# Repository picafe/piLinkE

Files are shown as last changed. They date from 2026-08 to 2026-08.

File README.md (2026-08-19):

# piLinkE

A compact USB-C clone of WCH's [WCH-LinkE](https://www.wch.cn/products/WCH-Link.html) debugger, designed in Altium. It programs and debugs WCH RISC-V MCUs over SWD, can be switched into DAPLink / ARM SWD mode, and has a USB-UART.

This is my own version, on a 4-layer PCB meant to be cheap to manufacture at JLCPCB, with more specific features.

Production files (Gerbers, drill, BOM) are in [`outputs/`](outputs/). Design files are in [`pcb/`](pcb/).

## Why this exists

I wanted an excuse to use Altium so I made this, which I consider to be a relatively simple board. The schematic follows the same overall design as existing OSHWHub clones ([fanhuacloud](https://web.archive.org/web/20240525210835/https://oshwhub.com/fanhuacloud/wch-linke/), with a CH32V305FBP6 as the LinkE MCU. As a bonus, the same chip can run [high-speed ARM DAPLink firmware](https://github.com/prosper00/CH32V305-DAPLink-HS).

## Pictures

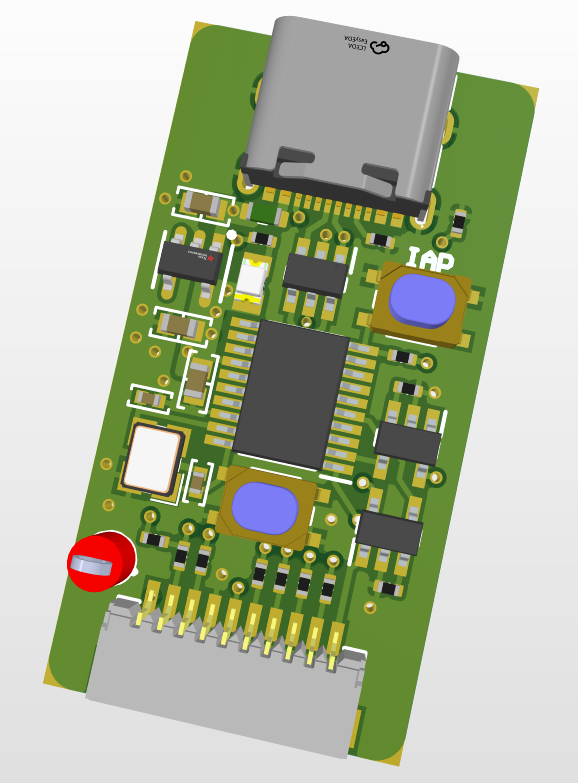
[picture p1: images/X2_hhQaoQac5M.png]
3D model


*3D model.*

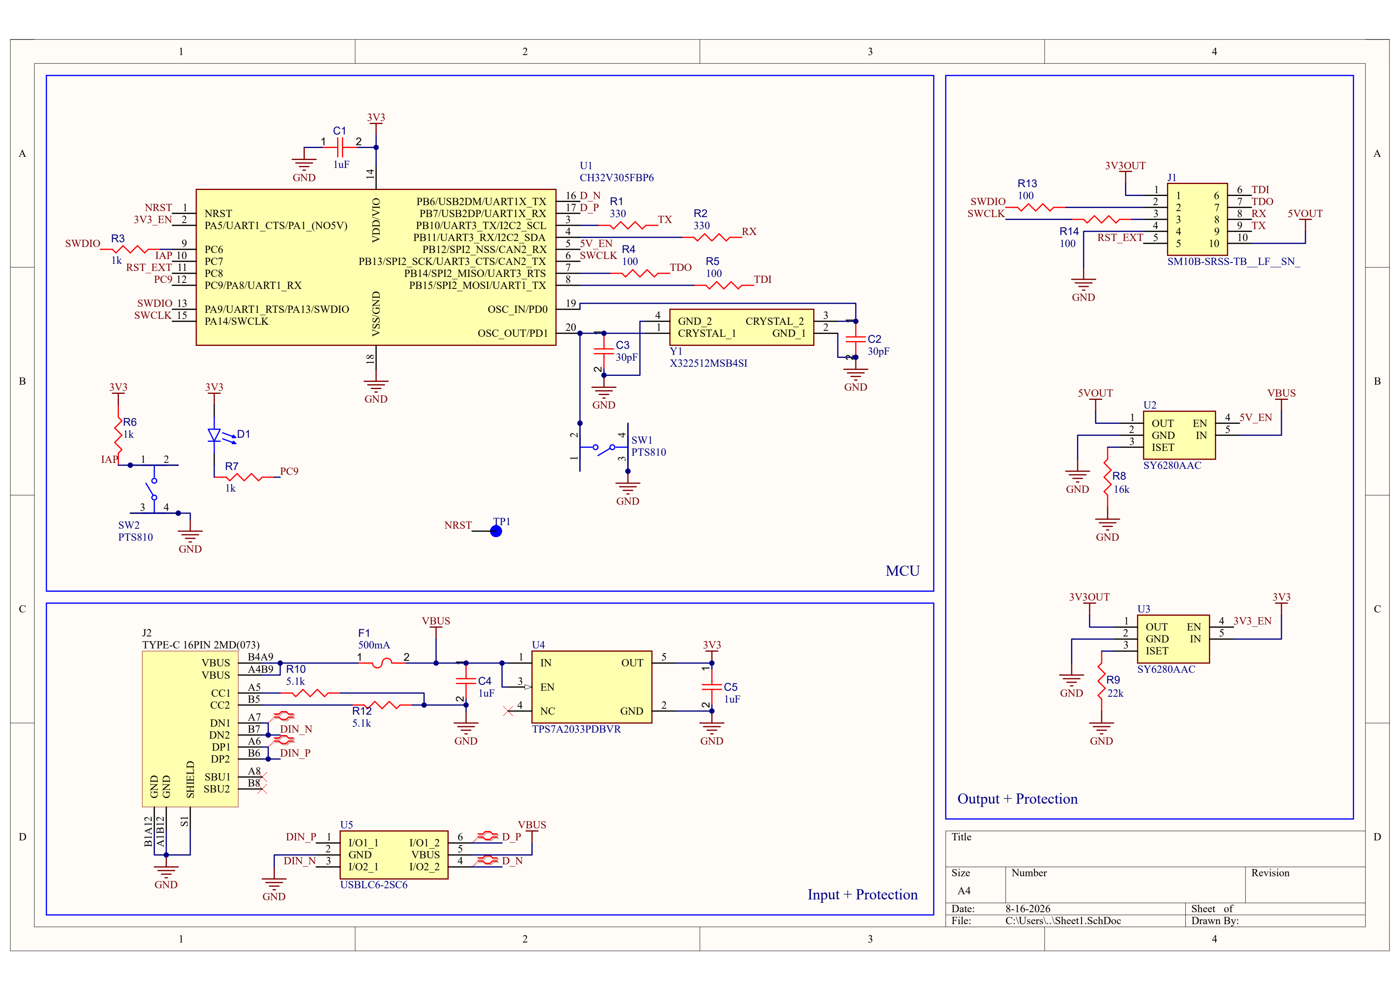
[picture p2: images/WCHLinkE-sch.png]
Schematic


*Schematic.*

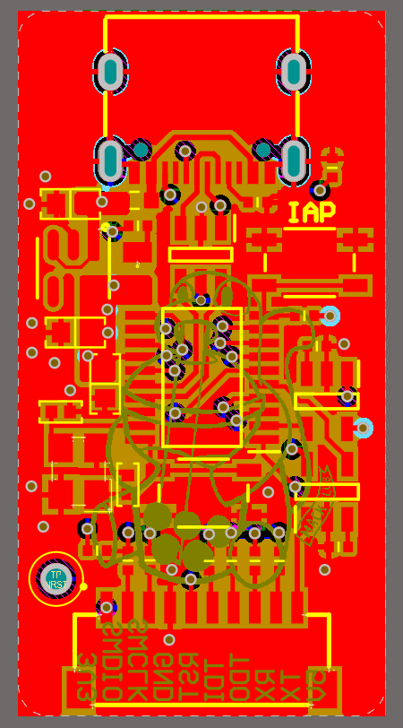
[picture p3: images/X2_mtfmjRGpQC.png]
PCB front


*PCB layout front*

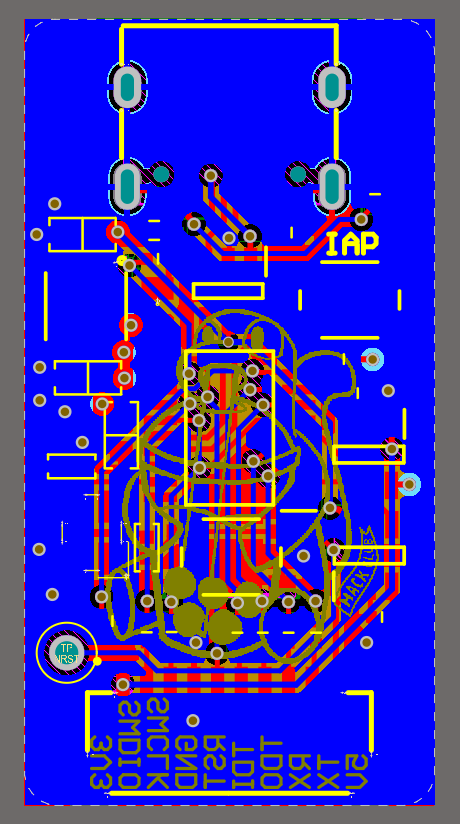
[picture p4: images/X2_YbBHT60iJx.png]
PCB back


*PCB layout back*

## Connections

The only cable is the target debug lead: a 10-pin JST-SH to Dupont harness.

The header pinout was copied so a stock **WeAct Studio Mini Debugger (ST-Link)** or **WeAct Logic Analyzer** JST-SH-to-Dupont cable is mostly colour-compatible.

Pin functions are also silkscreened on the board, next to the connector:

| Pin | Function |
| ---: | --- |
| 1 | 3V3 |
| 2 | SWDIO / TMS |
| 3 | SWCLK / TCK |
| 4 | GND |
| 5 | RST |
| 6 | TDI |
| 7 | TDO |
| 8 | RX |
| 9 | TX |
| 10 | 5V |

Buttons:

- **IAP** - hold while plugging in USB to enter IAP / bootloader mode
- **Mode** - hold while plugging in USB to switch RV (WCH) vs DAPLink mode

## How to flash

The CH32V305 needs WCH-LinkE firmware (or DAPLink, if you want ARM). Two options:

### Another WCH-LinkE

Use a working LinkE (or any WCH programmer) to flash `FIRMWARE_CH32V305.bin` onto this board over SWD, the same way you would program any other CH32V305.

### IAP, no second debugger

[wlink-iap](https://github.com/cjacker/wlink-iap) can upgrade / downgrade LinkE firmware over USB without holding the IAP button or buying a second dongle. Follow the instructions in that repo. Short version:

```
git clone https://github.com/cjacker/wlink-iap
cd wlink-iap
make
sudo make install

wlink-iap -f FIRMWARE_CH32V305.bin
```

For a full chip erase / APP+IAP image, enter IAP first (`wlink-iap -i`, or hold **IAP** while plugging in USB) and then follow the [wlink-iap](https://github.com/cjacker/wlink-iap) notes.

To leave IAP if you entered it by accident: `wlink-iap -q`.

After the stock LinkE firmware is on the board, use [WCH-LinkUtility](https://www.wch.cn/downloads/WCH-LinkUtility_ZIP.html) or MounRiver Studio to switch RV vs DAP mode.

## Known issues

- A few silkscreen-to-exposed-copper DRC errors were left as-is; they are cosmetic.
- Vias are tented. Altium's solder-mask sliver rule complains about vias close to exposed copper.

## Bill of materials

Prices are rough LCSC estimates (Aug 2026) and will move. They do not include the JST-SH cable.

| Designator | Value | Footprint | Qty | LCSC | Unit cost (est.) | Line total (est.) |
| --- | --- | --- | ---: | --- | ---: | ---: |
| C1, C4, C5 | 1 µF | 0603 | 3 | [C126631](https://www.lcsc.com/product-detail/C126631.html) | $0.08 | $0.23 |
| C2, C3 | 30 pF | 0402 | 2 | [C526980](https://www.lcsc.com/product-detail/C526980.html) | $0.005 | $0.01 |
| D1 | Green LED | 0805 | 1 | [C84256](https://www.lcsc.com/product-detail/C84256.html) | $0.01 | $0.01 |
| F1 | 500 mA PTC | 0603 | 1 | [C7472536](https://www.lcsc.com/product-detail/C7472536.html) | $0.04 | $0.04 |
| J1 | 10-pin JST-SH | SMD 1 mm | 1 | [C5340780](https://www.lcsc.com/product-detail/C5340780.html) | $0.07 | $0.07 |
| J2 | USB-C 16P | SMD | 1 | [C165948](https://www.lcsc.com/product-detail/C165948.html) | $0.19 | $0.19 |
| R1, R2 | 330 Ω | 0402 | 2 | [C25104](https://www.lcsc.com/product-detail/C25104.html) | $0.007 | $0.014 |
| R3, R6, R7 | 1 kΩ | 0402 | 3 | [C11702](https://www.lcsc.com/product-detail/C11702.html) | $0.007 | $0.021 |
| R4, R5, R13, R14 | 100 Ω | 0402 | 4 | [C25076](https://www.lcsc.com/product-detail/C25076.html) | $0.008 | $0.032 |
| R8 | 16 kΩ | 0402 | 1 | [C25759](https://www.lcsc.com/product-detail/C25759.html) | $0.016 | $0.016 |
| R9 | 22 kΩ | 0402 | 1 | [C25768](https://www.lcsc.com/product-detail/C25768.html) | $0.006 | $0.006 |
| R10, R12 | 5.1 kΩ | 0402 | 2 | [C25905](https://www.lcsc.com/product-detail/C25905.html) | $0.004 | $0.008 |
| SW1, SW2 | Tactile switch | SMD | 2 | [C5363473](https://www.lcsc.com/product-detail/C5363473.html) | $0.03 | $0.06 |
| TP1 | Test point | Through hole | 1 | [5000](https://www.digikey.com/en/products/detail/keystone-electronics/5000/301) | $0.25 | $0.25 |
| U1 | CH32V305FBP6 | TSSOP-20 | 1 | [C5123443](https://www.lcsc.com/product-detail/C5123443.html) | $1.90 | $1.90 |
| U2, U3 | SY6280AAC | SOT-23-5 | 2 | [C55136](https://www.lcsc.com/product-detail/C55136.html) | $0.10 | $0.19 |
| U4 | TPS7A2033PDBVR | SOT-23-5 | 1 | [C2862740](https://www.lcsc.com/product-detail/C2862740.html) | $0.24 | $0.24 |
| U5 | USBLC6-2SC6 | SOT-23-6 | 1 | [C2827654](https://www.lcsc.com/product-detail/C2827654.html) | $0.04 | $0.04 |
| Y1 | 12 MHz | 3225 | 1 | [C9002](https://www.lcsc.com/product-detail/C9002.html) | $0.10 | $0.10 |
| | | | | **Total (components only)** | | **~$3.43** |

The PCB + stencil cost is around $10 on JLCPCB.

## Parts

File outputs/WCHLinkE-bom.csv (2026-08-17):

Name | Description | Designator | Footprint | LibRef | Quantity | LCSC
Capacitors,C126631,1uF | Capacitor | C1, C4, C5 | CAP 0603_1608 | Capacitors | 3 | C126631
Capacitors,C526980,30pF | Capacitor | C2, C3 | CAP 0402_1005 | Capacitors | 2 | C526980
KT-0805G | -40?~+85? 100mW 120° 2.6V~3.1V 430mcd 513nm~528nm 525nm 5mA Emerald Green 0805 LED Indication - Discrete ROHS | D1 | KT-0805G | CMP-007-00006-5 | 1 | C84256
Fuses,500mA,C7472536 | Fuse | F1 | LFUS-467_V | Fuses | 1 | C7472536
SM10B-SRSS-TB__LF__SN_ | Connector | J1 | SM10B-SRSS-TB | SM10B-SRSS-TB__LF__SN_ | 1 | C5340780
TYPE-C 16PIN 2MD(073) | USB-C (USB TYPE-C) Receptacle Connector 16 Position Surface Mount, Right Angle | J2 | USB-C-SMD_TYPE-C-16PIN-2MD-073 | TYPE-C_16PIN_2MD_073 | 1 | C165948
Resistors,C25104,330 | Resistor | R1, R2 | RESC0402(1005)_L | Resistors | 2 | C25104
Resistors,C11702,1k | Resistor | R3, R6, R7 | RESC0402(1005)_L | Resistors | 3 | C11702
Resistors,C25076,100 | Resistor | R4, R5, R13, R14 | RESC0402(1005)_L | Resistors | 4 | C25076
Resistors,C25759,16k | Resistor | R8 | RESC0402(1005)_L | Resistors | 1 | C25759
Resistors,C25768,22k | Resistor | R9 | RESC0402(1005)_L | Resistors | 1 | C25768
Resistors,C25905,5.1k | Resistor | R10, R12 | RESC0402(1005)_L | Resistors | 2 | C25905
PTS810 | SWITCH TACTILE SPST-NO 0.05A 16V | SW1 | FP-PTS810_SJG_250_SMTR_LF-MFG | CMP-10040-000011-1 | 1 | C5363473
PTS810 | SWITCH TACTILE SPST-NO 0.05A 16V | SW2 | FP-PTS810_SJG_250_SMTR_LF-MFG | CMP-10040-000011-1 | 1 | C5363473
5000 | Test Point Miniature THM H .300 Nylon 46 Insulated Red PhosBronze/Silver | TP1 | KEYSTONE_5000 | CMP-246-000000-1 | 1
CH32V305FBP6 | Integrated Circuit | U1 | SOP65P640X110-20N | CH32V305FBP6 | 1 | C5123443
SY6280AAC | Integrated Circuit | U2, U3 | SOT95P285X140-5N | SY6280AAC | 2 | C55136
TPS7A2033PDBVR | IC REG LINEAR 3.3V 300MA SOT23-5 | U4 | FP-DBV0005A-IPC_B | TPS7A2033PDBVR | 1 | C2862740
USBLC6-2SC6 | Integrated Circuit | U5 | SOT95P280X145-6N | USBLC6-2SC6 | 1 | C2827654
X322512MSB4SI | Crystal or Oscillator | Y1 | X322512MSB4SI | X322512MSB4SI | 1 | C9002

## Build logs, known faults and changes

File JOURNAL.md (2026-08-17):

# July 24, 2026: Started the schematic and sourced symbols

After watching [this](https://www.youtube.com/watch?v=FJ3fFXFcsLk) video on youtube, I thought this would be a nice project to do as I thought the WCHLinkE is quite expensive for what it is on Aliexpress (~$7). At the same time, I wanted to learn how to use Altium and be comfortable using it more, so I decided it would be good practice.

After some very brief research, I found other similar projects on the Chinese version of Oshwstar (Oshwstar), mostly the following which had almost the same overall design:
https://web.archive.org/web/20240525210835/https://oshwhub.com/fanhuacloud/wch-linke/
https://oshwhub.com/huashuo0804/wch-linke

I also found this, which will let me use the WCHLinkE as a high speed ARM DAP Link debugger, which is a nice feature to have:
https://github.com/prosper00/CH32V305-DAPLink-HS

I opened up Altium and began trying to place all the symbols on the board, since this would very much be the most tedious part (sourcing symbols).

For USB-C, I wanted to be sure I had the same FP as the component I was getting, so I used [a tool]() to convert LCSC/EasyEDA components into Altium symbols and FPs and manually copy pasted the component from the library into my own library for the project. However, I very much dislike the way EasyEDA lays out their USB-C symbol as you can see:

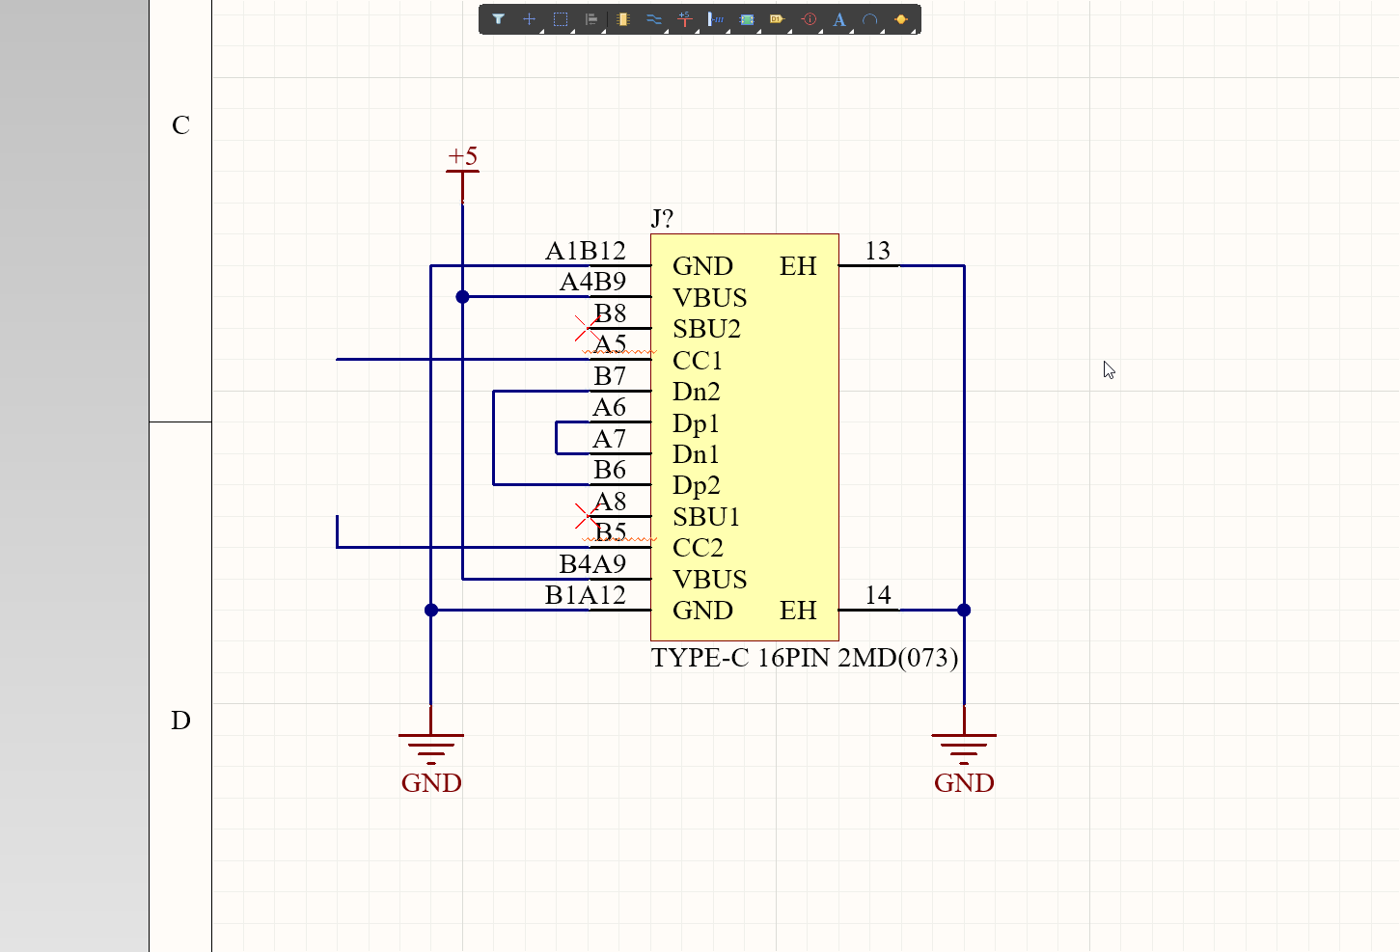
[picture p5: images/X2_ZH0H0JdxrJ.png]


I ended up opening another window of KiCad and opening up the USB-C symbol from there and copying overall layout of the symbol in Altium. I used SamacSys Altium LL to get the CH32 symbol, but again it was fairly messy when I tried to use it, so I ended up doing the same process of copying the layout of the KiCad symbol.

I also had to manually add and adjust the 3D model for the USB-C connector, since the one from  was not quite right.

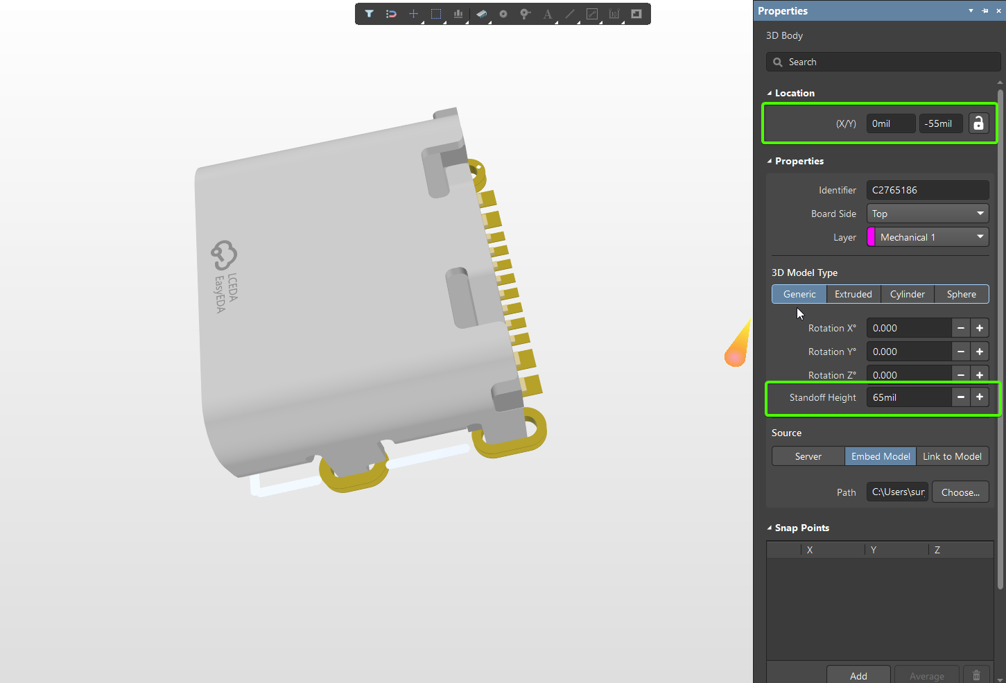
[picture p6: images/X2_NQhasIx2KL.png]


I also tried importing directly from KiCad into Altium with the KiCad import tool plugin, but it maintained a lot of the KiCad formatting (fonts, line widths, text sizes, etc.), which didn't look too good in Altium.

After some work, I finally got most of the components placed:

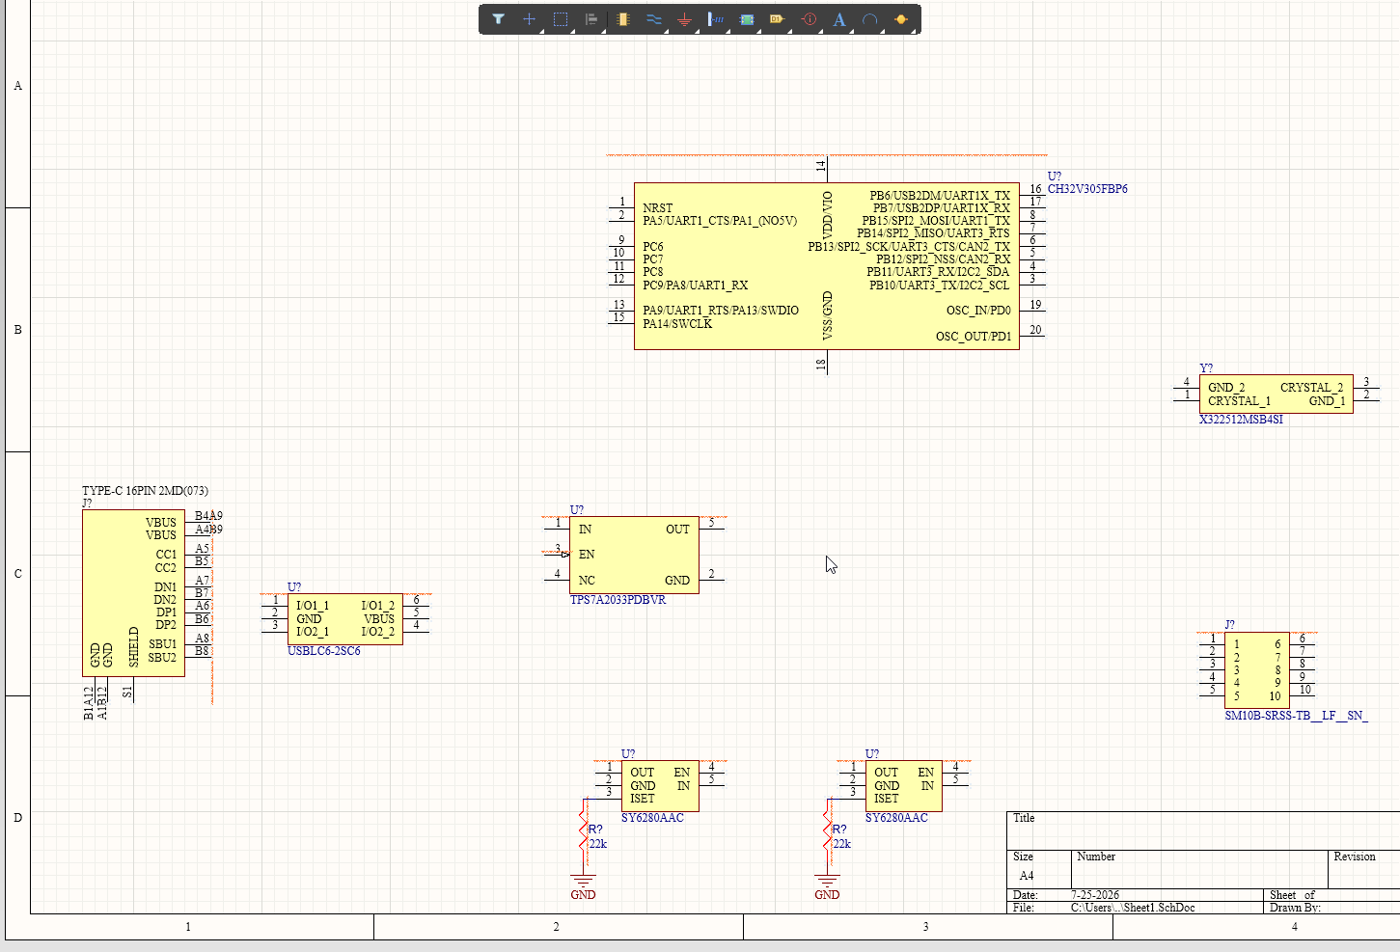
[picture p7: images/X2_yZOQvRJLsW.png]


**Total time spent: 3.5 hours**

# July 25, 2026: Placed components and configured design rules

I started on the passives, which were just generic components from my org's component library which I added LCSC number properties to after finding a suitable LCSC part for each in the schematic. For the custom parts, I used the property editor in the schematic library and for generic parts, I edited the properties in the schematic.

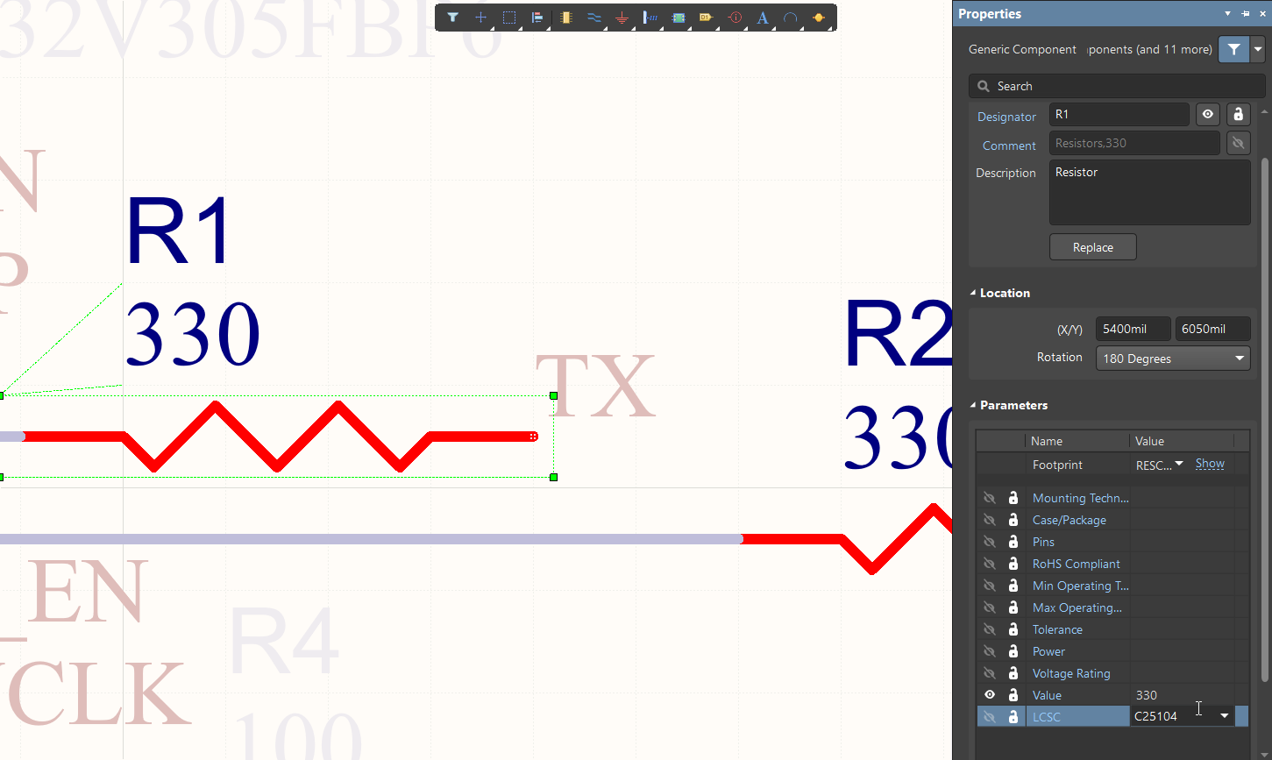
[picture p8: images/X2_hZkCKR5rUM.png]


The footprints I mostly used the default for the symbols, and the footprints in my org's library for the passives after adding the values to each.

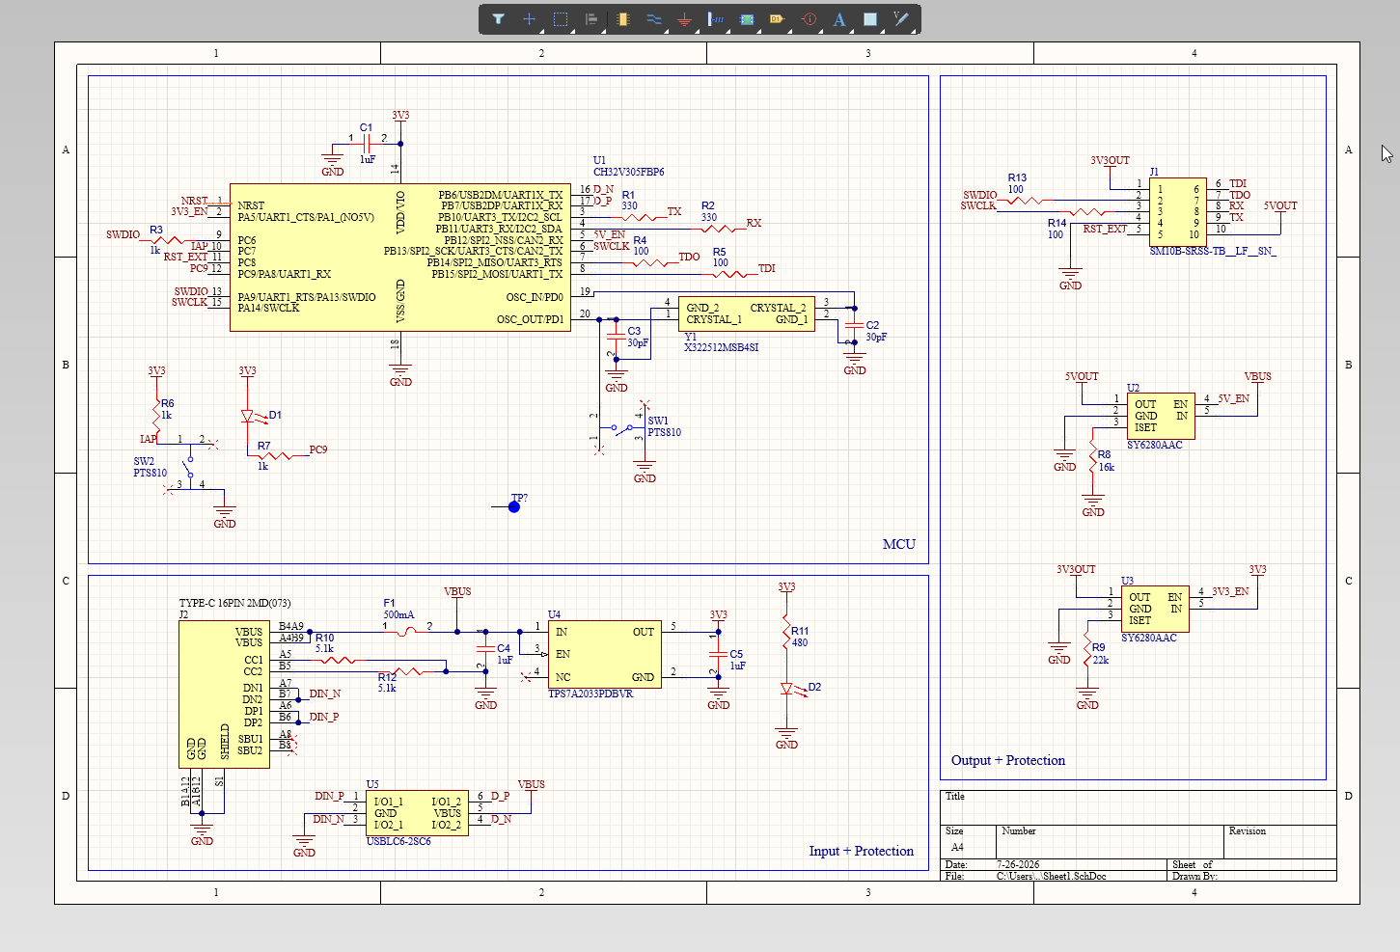
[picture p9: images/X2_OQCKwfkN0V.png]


I also cleaned up the schematic as you can see, and finally ran an ERC check to make sure I didn't miss anything.

I then ran the ECO to apply the changes to the PCB, which had no errors (yay!).

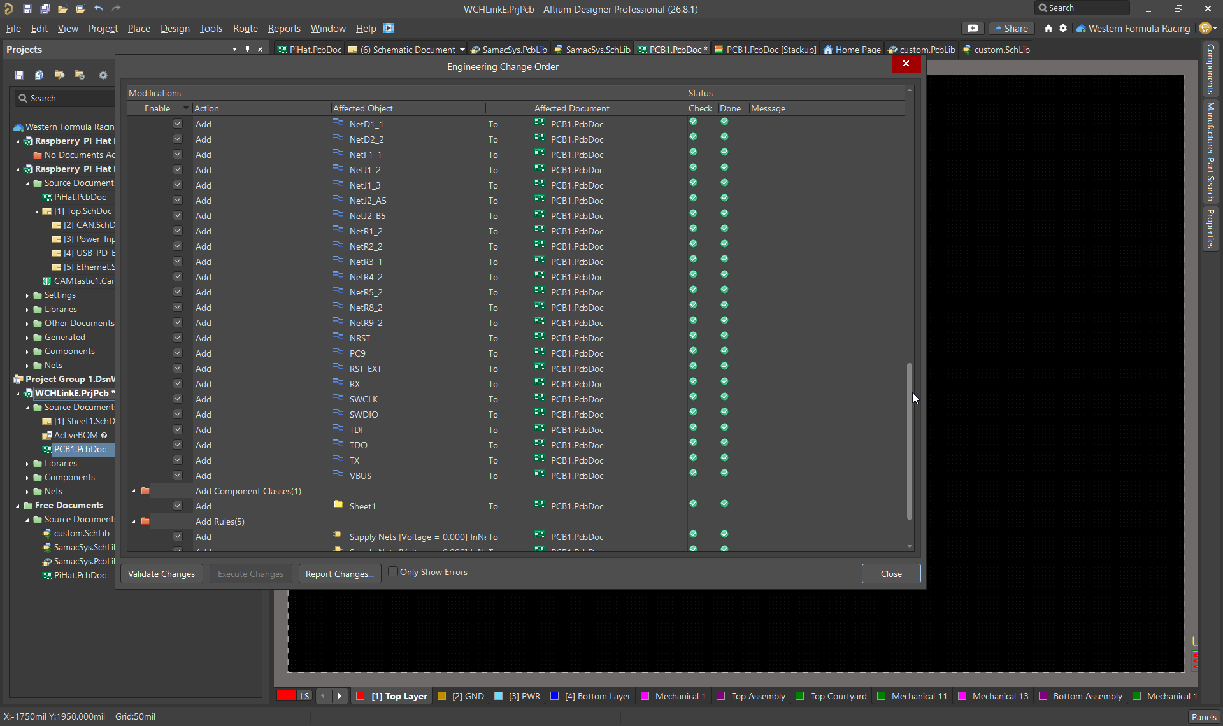
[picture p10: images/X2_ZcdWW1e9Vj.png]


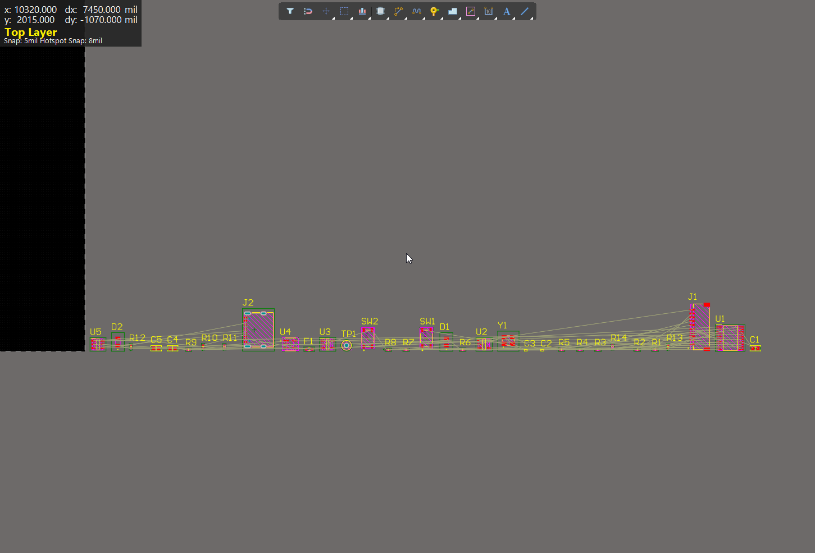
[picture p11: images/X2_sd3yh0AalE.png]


The first thing I noticed after grouping the components together and zooming in was the rule violations on the TSSOP and USB-C pads (green highlighted) which were caused by the spacing between the pads. I had never setup a new project before, so after some searching it seemed that default clearances were set to defaults that are uncommon (10 mil for every clearance type), so I had to explore the rules manager to adjust the clearances.

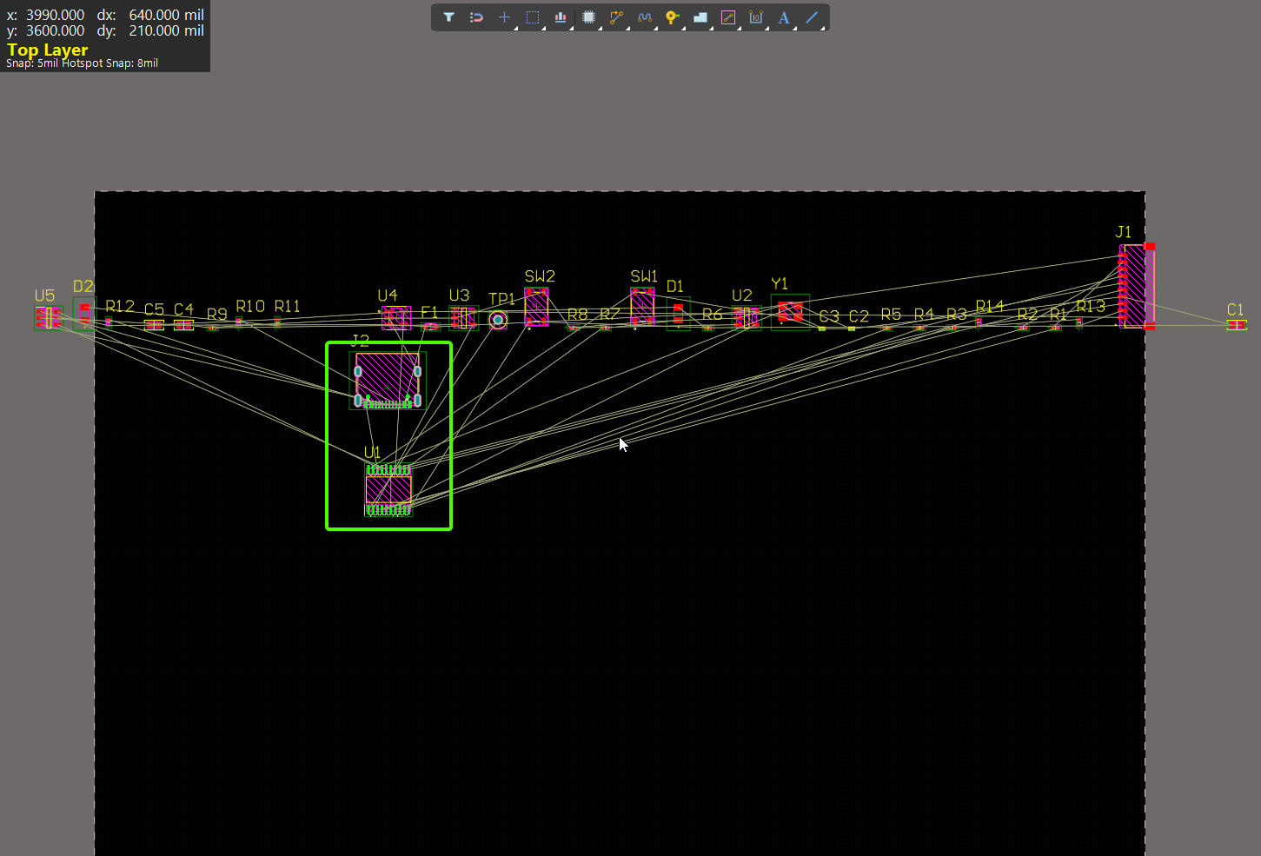
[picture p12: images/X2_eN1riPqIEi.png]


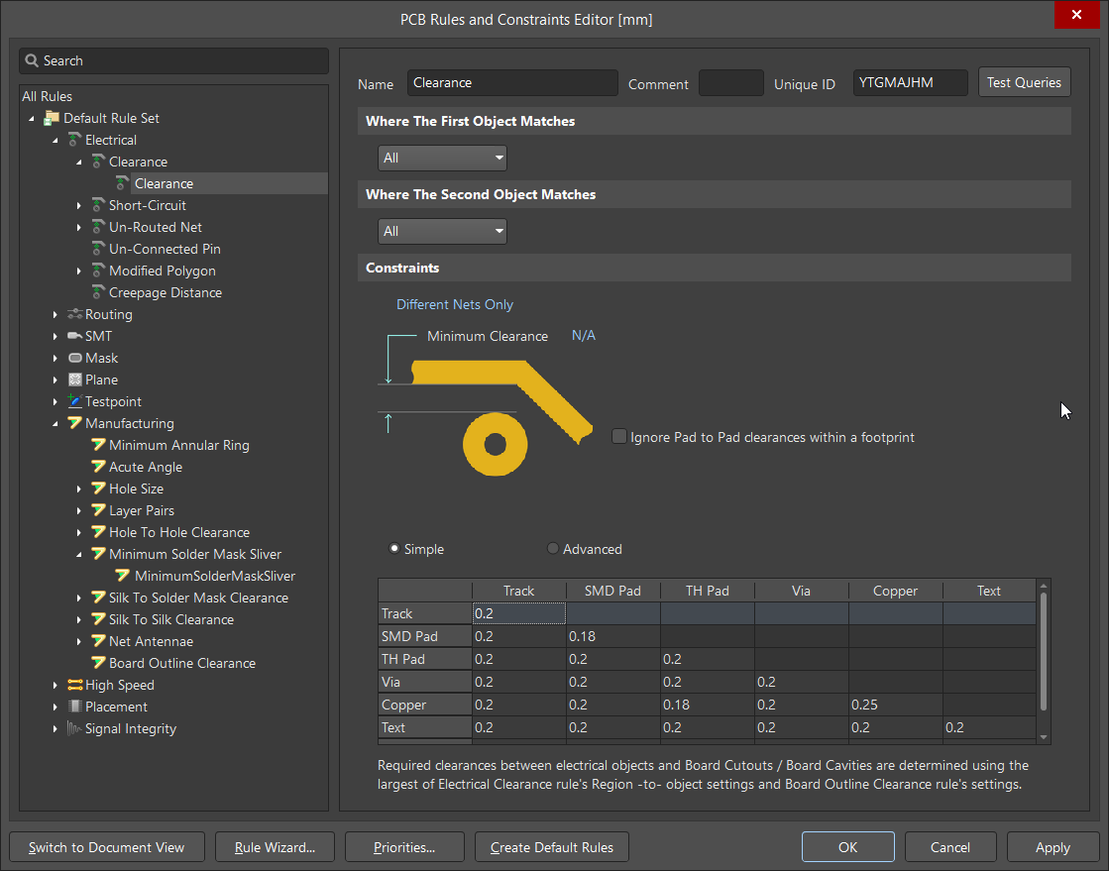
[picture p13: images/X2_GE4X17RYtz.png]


After doing that, I started component placement:

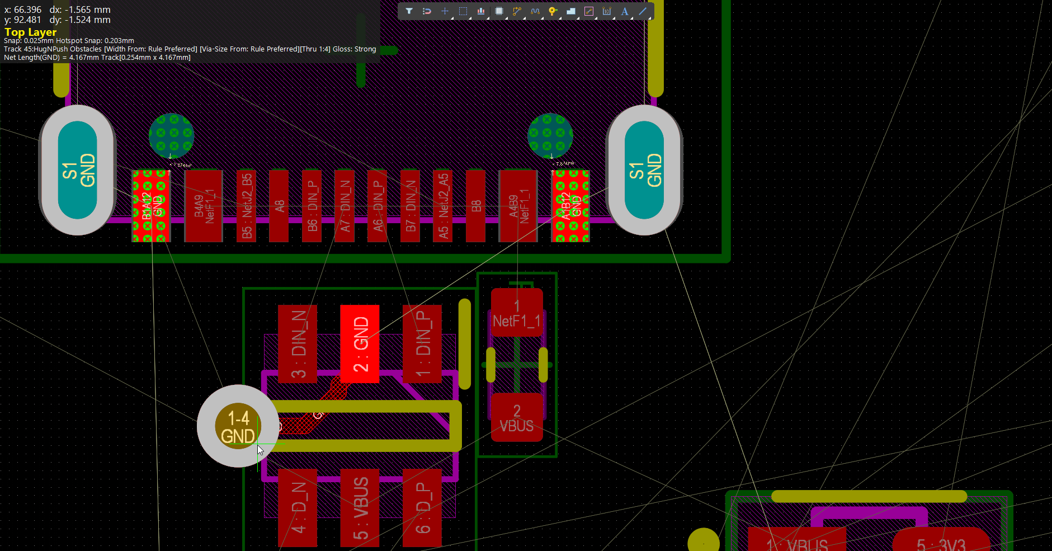
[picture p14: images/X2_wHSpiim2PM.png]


I had to adjust the default via diameter and pad radius since the defaults were surprisingly large.

This is what I had roughly after getting used to navigating Altium:

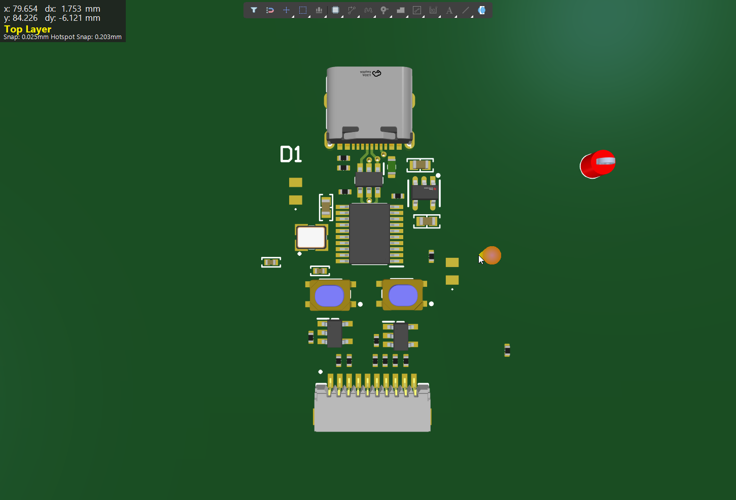
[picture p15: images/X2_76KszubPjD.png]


One thing I had to fix was the keepout area for some components. For some reason, the keepout clearance included the silkscreen of the component (since I guess it's a primitive layer), so I had to manually make the keepout smaller for the LED pads and change the pin indicator to be under the component.

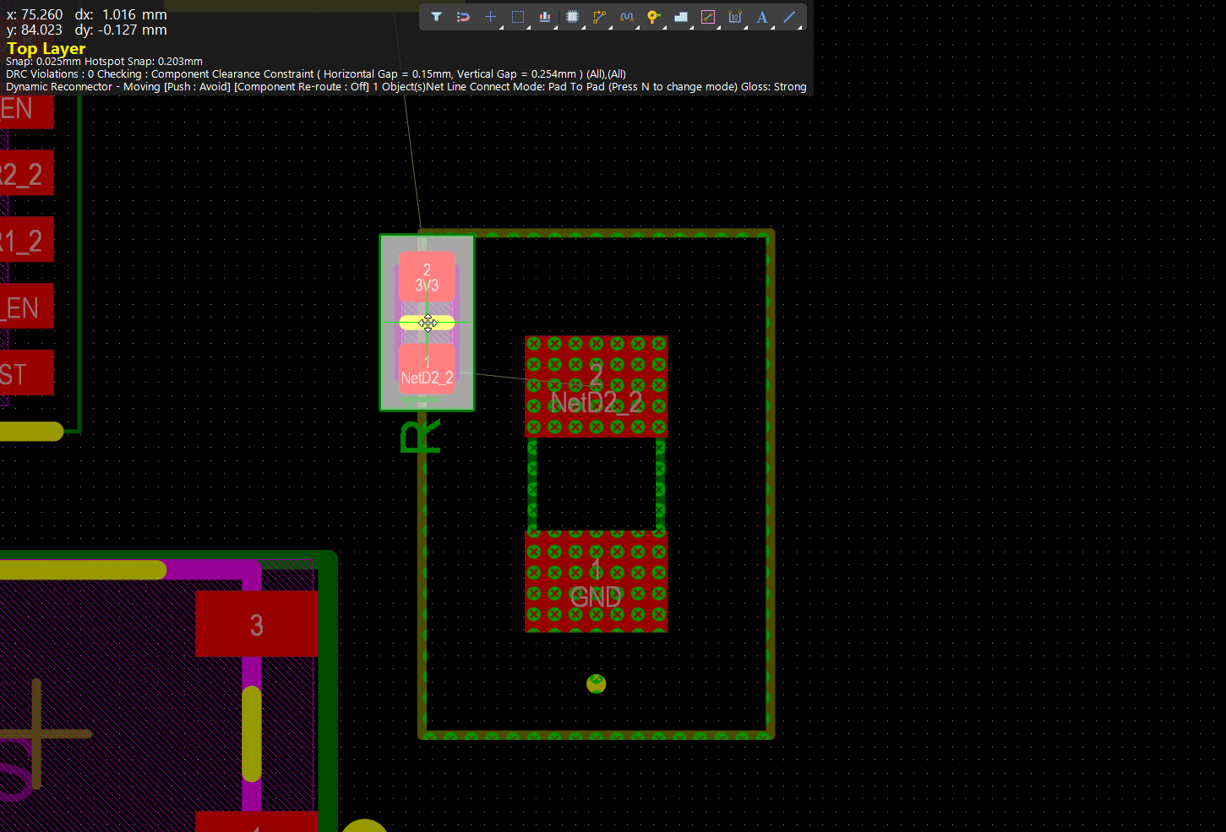
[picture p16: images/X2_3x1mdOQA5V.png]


This took quite a while since I had to hunt down the footprint in my org's library and adjust it there, but after trying to do that for a while, I just gave up and updated the primitive on the board directly (unlocking primitive layers to edit them).

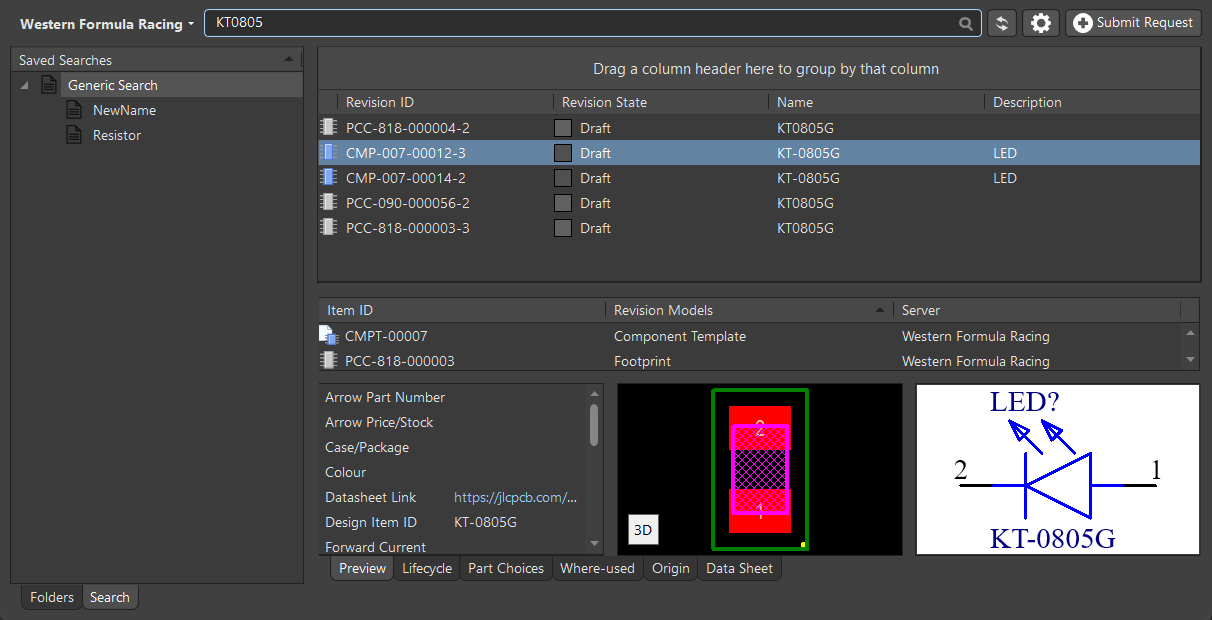
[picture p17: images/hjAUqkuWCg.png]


Then, I decided to setup the impedance control for the USB differential pairs, which I had to search up a tutorial how to do. Since Altium does it's own calculations for the trace width and gap based on board spec, I had to find the exact JLC board spec instead of using their impedance calculator. Overall, I ended up with the following, which is almost the same as the impedance calculator's results:

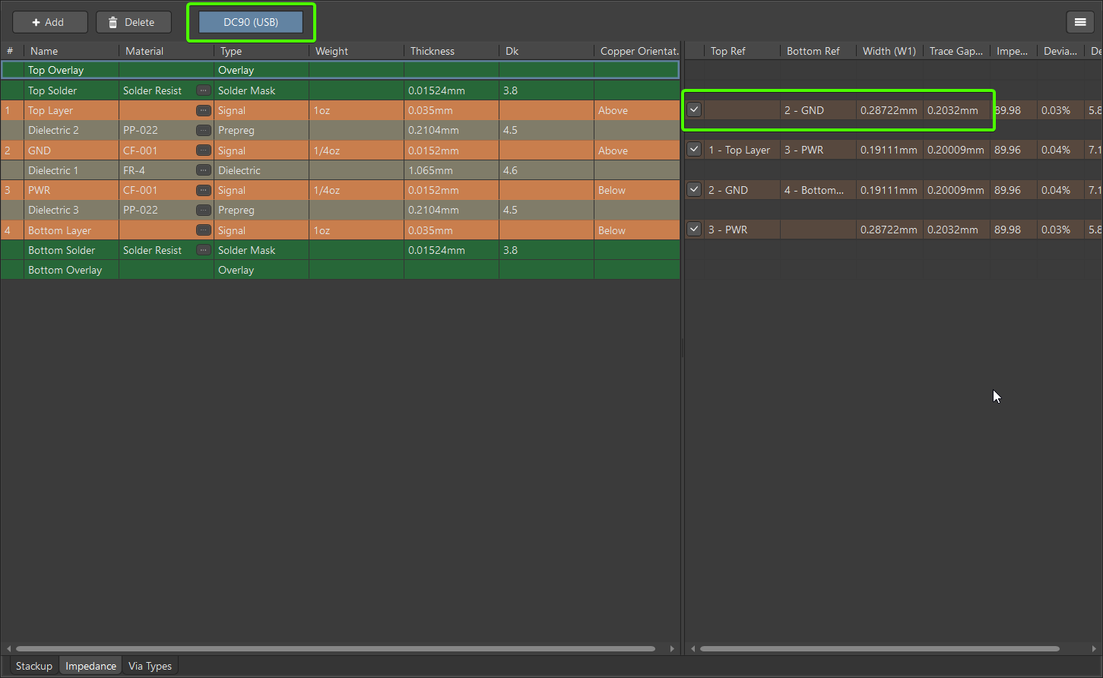
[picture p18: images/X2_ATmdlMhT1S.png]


This was the guide I followed and it was very helpful: https://www.youtube.com/watch?v=ULK_fRNbZcs

**Total time spent: 5 hours**

# July 29, 2026: Routed most of the board

I started (and basically finished) most of the routing for the board, although there is still quite a bit of work to be done. I still need to route the power traces, planes, and some other minor things. I also had to search on how to adjust the board outline, but it was fairly simple. I did this while crammed in the middle seat of a plane so I wasn't the most efficient with my trackpad.

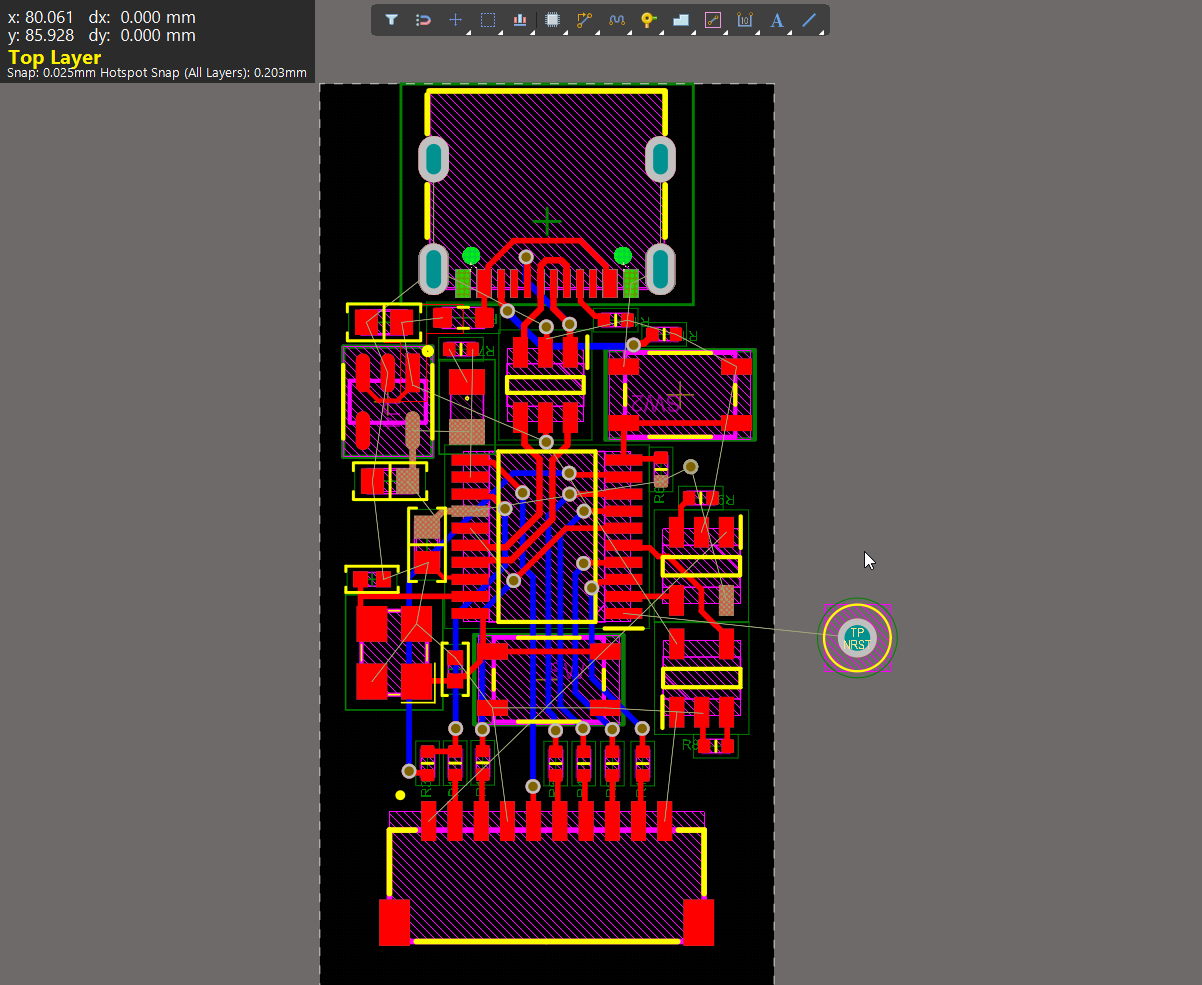
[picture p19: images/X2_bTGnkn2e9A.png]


**Total time spent: 3 hours**

# August 10, 2026: Routed power and filled copper planes

I started with routing the power traces, and then moved on to planes which was a bit harder than I thought. I got ground planes to work (or at least I thought) but local polygons inside the ground plane didn't seem to fill. After some searching, I used the polygon manager to order based on fill priority, change the property to fill over all items with the same net, and then force refill all the polygons. I also used this to duplicate the GND plane and move it to the GND layer and bottom layer.



After that, the PCB finally looked almost finished:

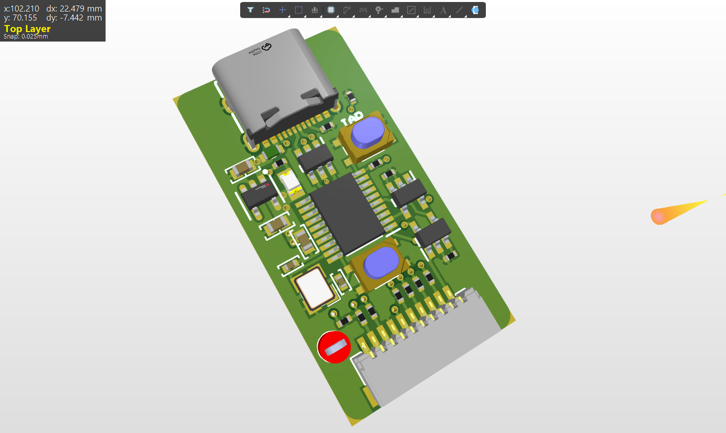
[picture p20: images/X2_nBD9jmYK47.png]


**Total time spent: 1.2 hours**

# August 14, 2026: Ran DRC and added silkscreen

I ran DRC for the first time, which was quite interesting. Other than a few stray traces, the only errors seemed to be spam from me not setting proper values in the rules manager correctly, except I had pretty much no idea what the rule violations were. 

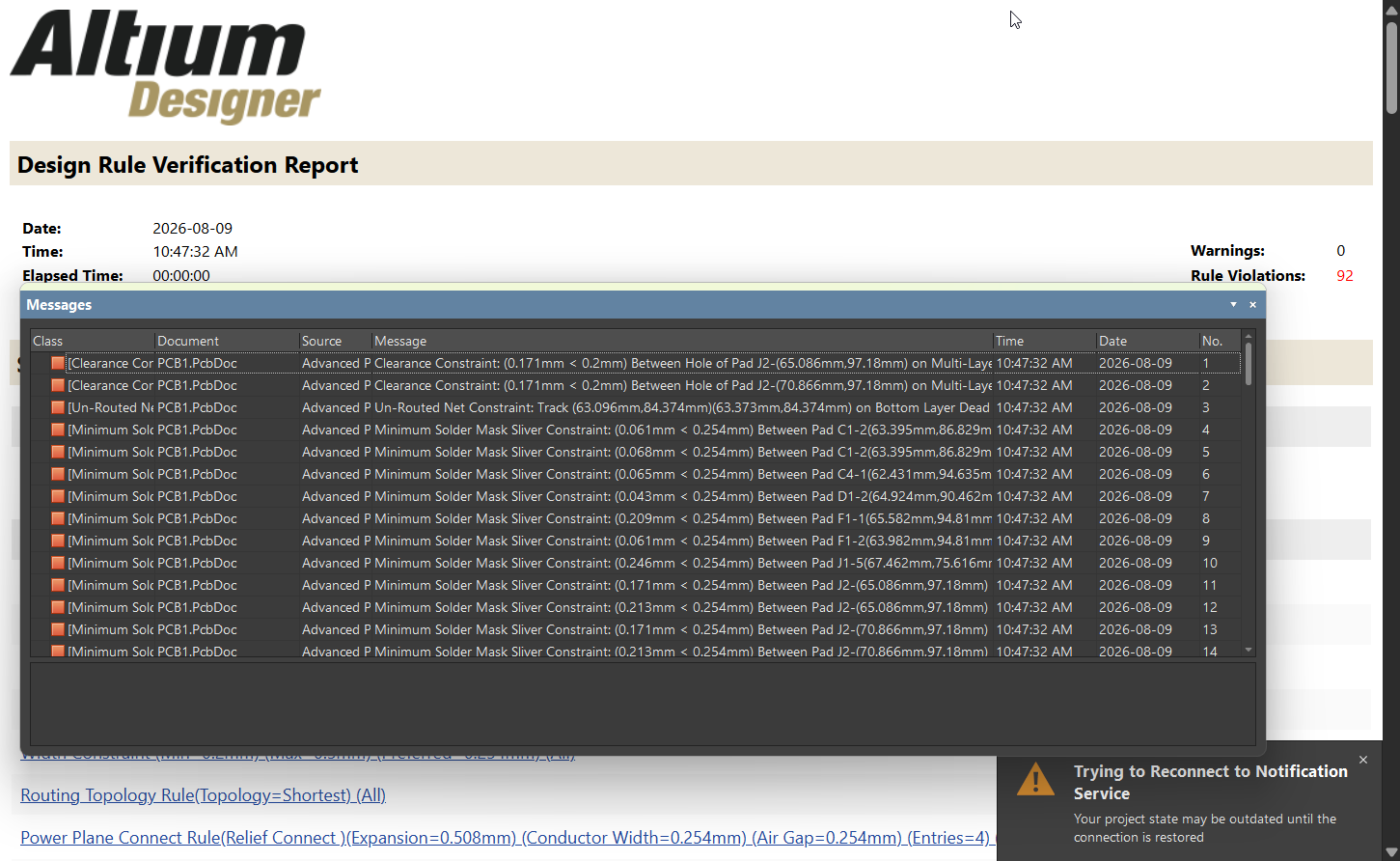
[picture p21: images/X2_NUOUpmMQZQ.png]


The main issue was minimum solder mask silver constraint, which turns out to represent the width of narrowest gap between 2 regions of area without solder mask. Since I had vias in my planes to connect to ground and power planes, it basically meant I had to adjust the constraint to be smaller and move the vias a bit further away, although the vias will be tented anyways so it shouldn't be a problem (apparently from a quick search there's no option to set this in Altium that isn't convoluted). There were also violations in areas where silkscreen was too close to areas of exposed board, which I just decided to ignore since it's not a big deal.

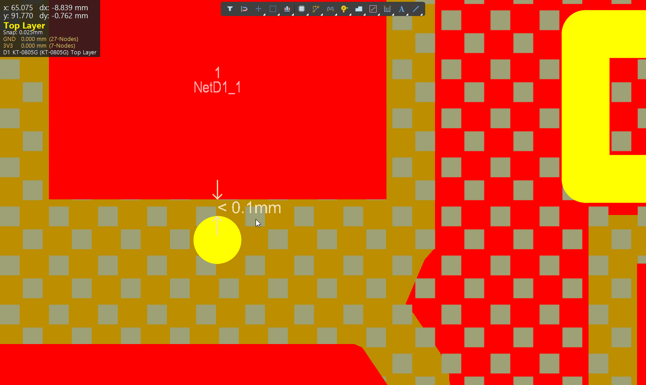
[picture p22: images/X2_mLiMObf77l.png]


After that, I started adding things on the silkscreen; some labels to the board for the 10 pin JST connector to help me identify the pins of the WCHLinkE and orpheus drinking boba. Lastly, I fixed some minor things such as consistent track widths (I had some data tracks that were 0.3mm wide instead of 10mil, which was the default and which I left it at), and rounding the board edges.

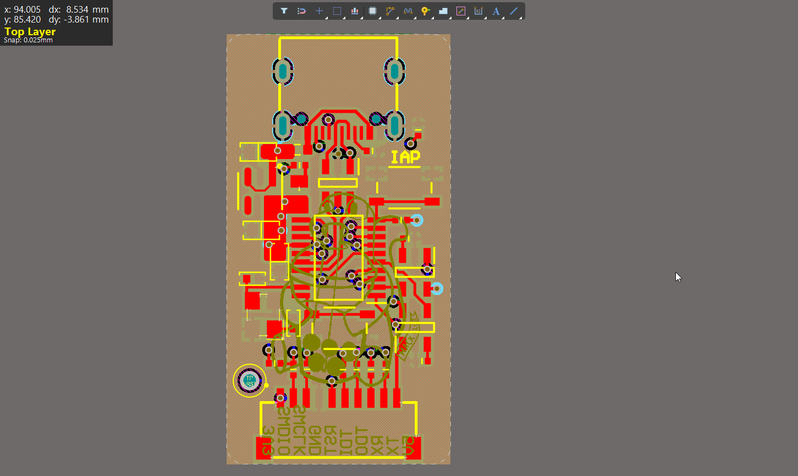
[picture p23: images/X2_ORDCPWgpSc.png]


**Total time spent: 1.5 hours**

# August 15, 2026: Exported production files

Exporting prod files (gerber, drill, bom csv) was quite similar to how it is on KiCad if you do it manually (without the JLCPCB production file extension). Took me a bit to do since JLC doesn't support gerber X2 exports, which is what the youtube guide told me to do. 

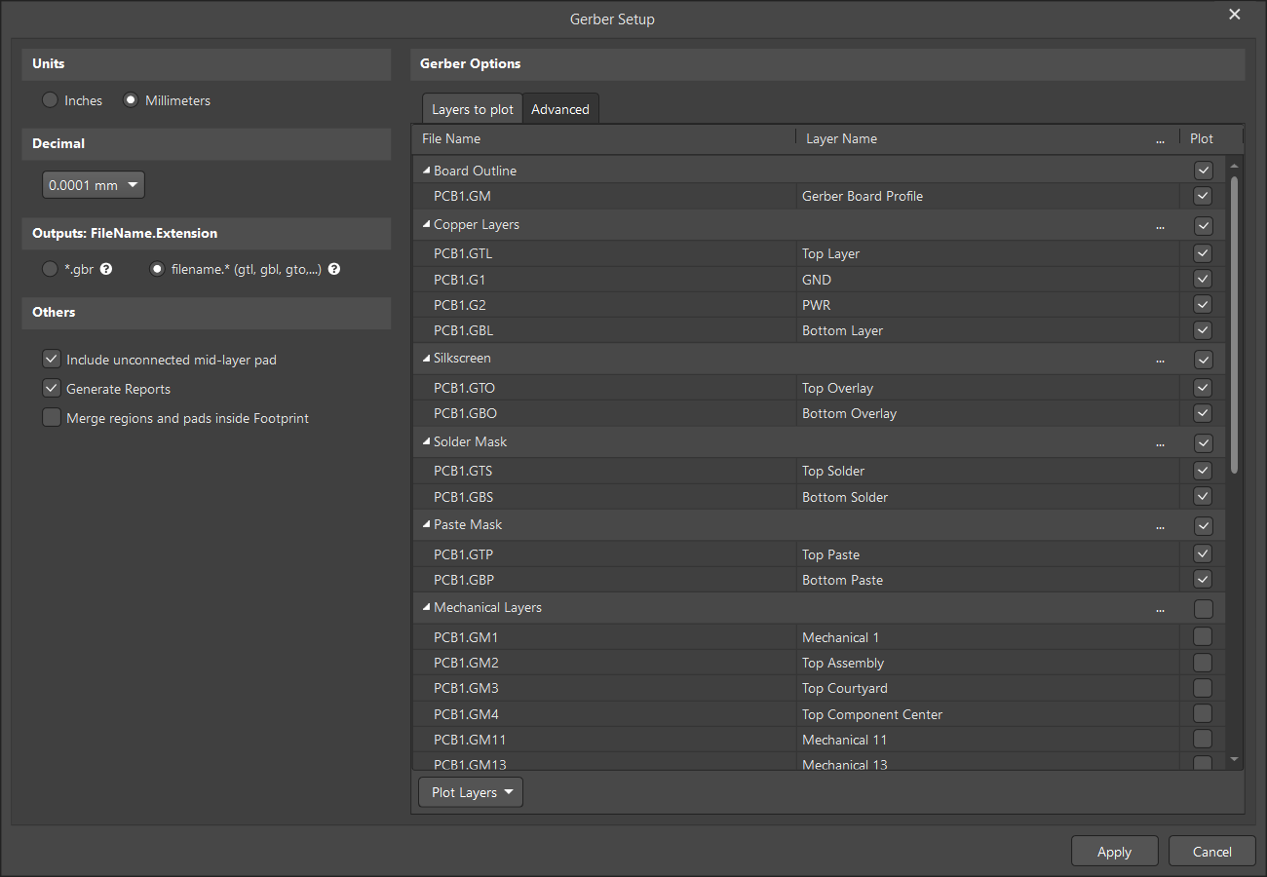
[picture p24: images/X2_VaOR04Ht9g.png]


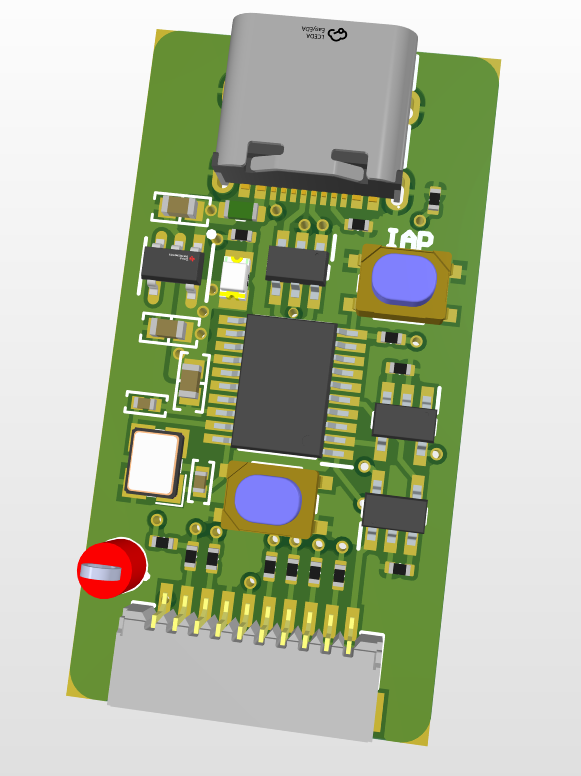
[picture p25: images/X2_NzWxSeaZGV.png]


**Total time spent: 0.4 hours**

# August 16, 2026: Final touches

One thing I forgot to do earlier was add stitching vias for the GND plane, but after doing that I realized that my vias had thermal reliefs (which idk how I didn't really notice until now). 

I looked into rules manager and first found this under advanced plane connect style, which I adjusted but after refilling polygons, it was still the same.

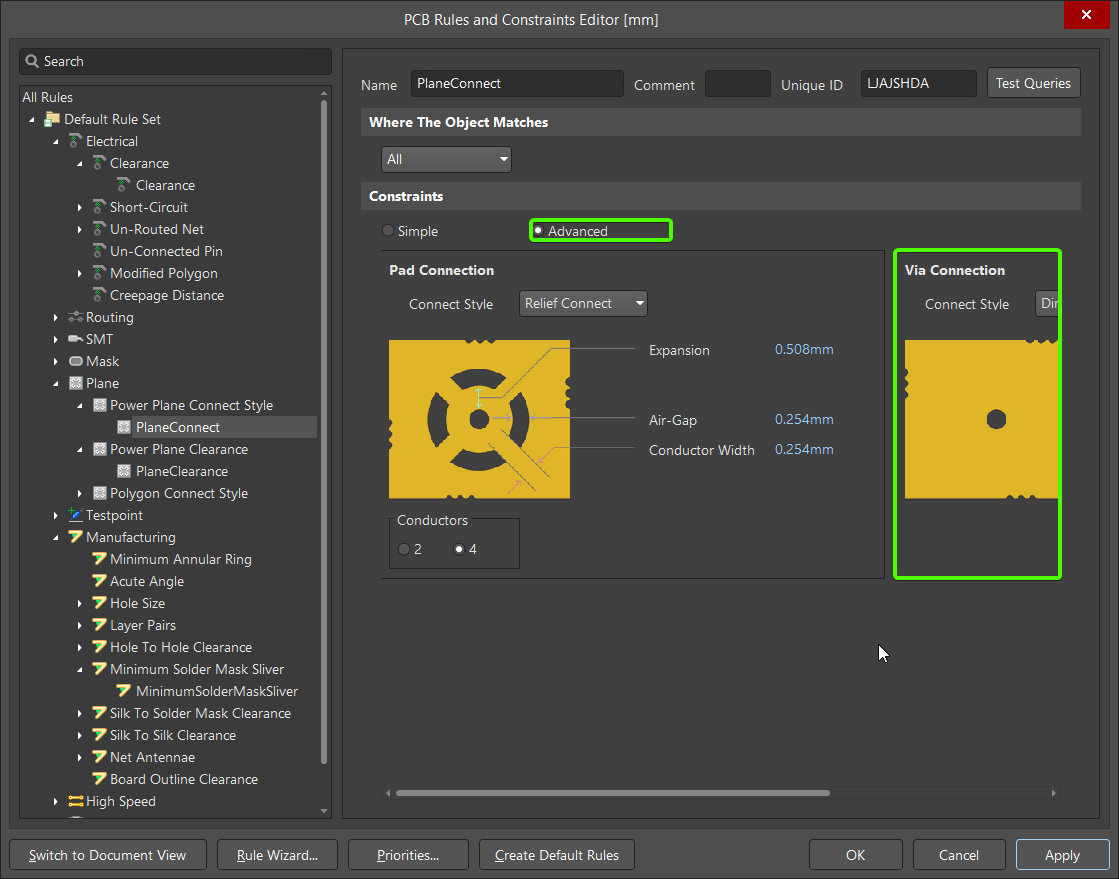
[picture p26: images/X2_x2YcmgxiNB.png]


I forgot earlier that I added plane connects by net since I wanted to have entirely solid connects for vias in internal layers, so the way I did it might not have been the best way, since I could have just use the advanced plane connect style to have solid connects for vias in all polygons/layers.

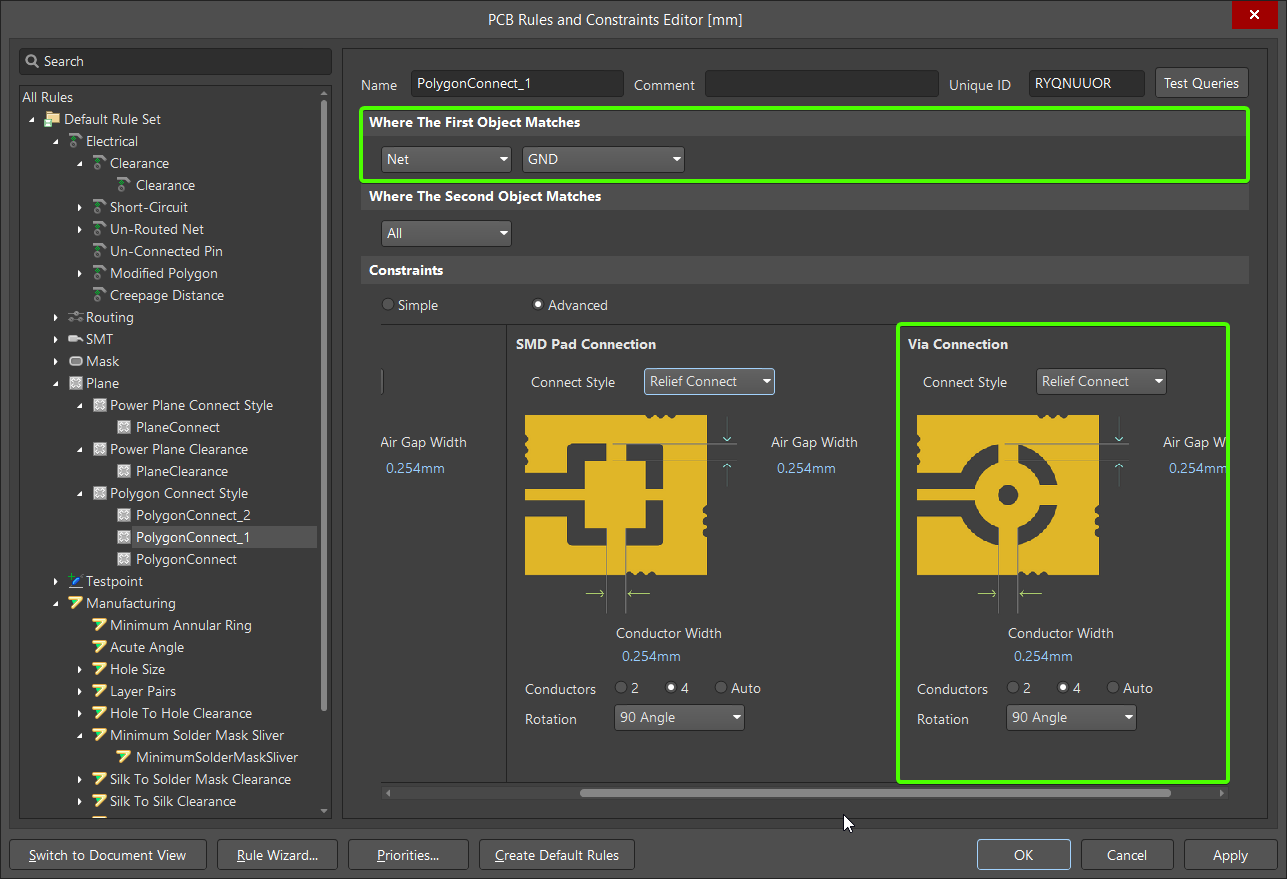
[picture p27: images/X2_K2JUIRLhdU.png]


Anyways, this is what it looks like now:

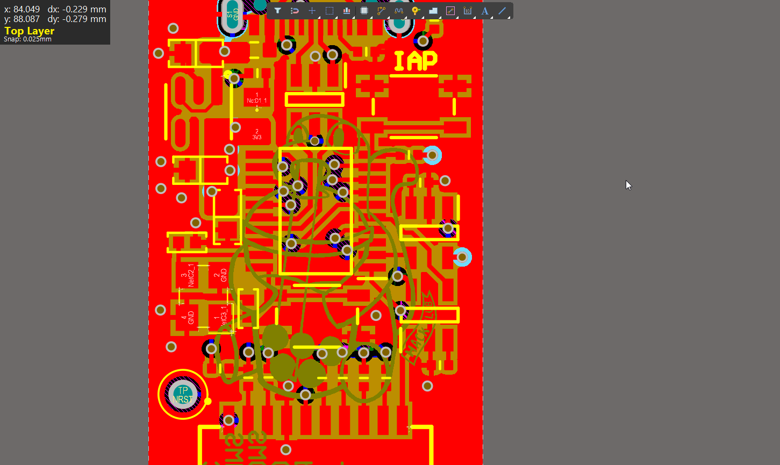
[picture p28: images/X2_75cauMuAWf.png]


I breifly ran DRC, and then re-exported the production files.

**Total time spent: 0.5 hours**
